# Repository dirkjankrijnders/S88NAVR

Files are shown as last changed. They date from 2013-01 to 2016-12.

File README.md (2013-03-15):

S88NAVR
=======

An implementation of the S88-N protocol for Atmel Atmega[8/48/88/168/328] microcontrollers. So far, an Arduino Pro Mini version and the actual board have been tested.

Goal
----

The goal is the make small, cheap reliable feedback modules for the S88 system. Hence choice for the microcontroller, one IC instead of the three discreet ones. The choice for SMD technology for a small board with components on both sides, as most will be hand soldered. The reliability comes from the use of the S88-N Cabling and timing, input diodes and a RC input network. If wanted the RC network and diodes can be short to minimize cost when needed, leaving 10 components (2 connectors, an uc, two caps and five resistors). The RC-network kills spike, the 1N4148 does the same ensuring the reliability of the detection, the big diode make sure the "detection" rail acts a as a ground return as well ensuring reliable operation of the track. 
The board is designed for production by cheap production houses like seeedstudio's PCB service. Goal is to stay under €5.00 for the fully build PCB.

State
-----
The parts for the first revision (Rev. 0) have been ordered, including the PCB at Seeedstudios. See below for an image and a BOM of the non-standard parts.
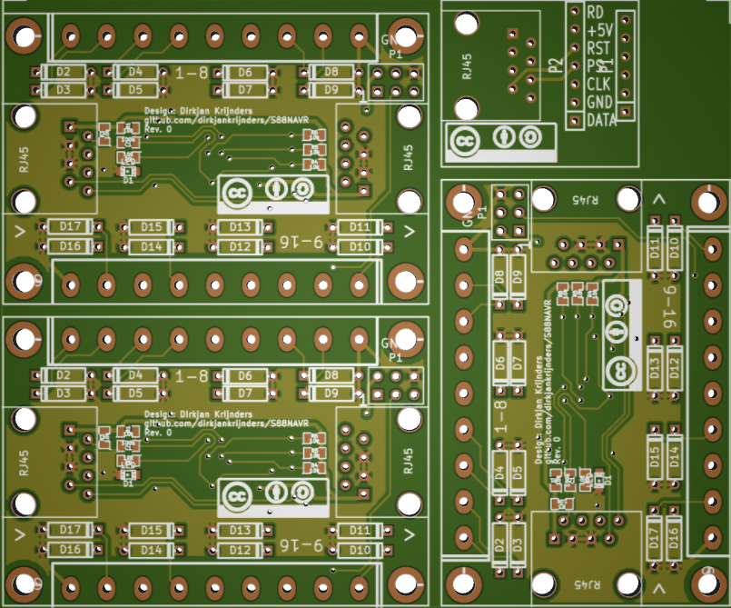
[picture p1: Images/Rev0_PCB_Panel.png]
. The total is still enough under €5.00 to fit the passives and stand-offs (no prices because then come from my stock).
<table>
<tr>
<th>Part</th><th>#</th><th>Conrad #</th><th>price* (€)</th>
</tr>
<tr><td>IC1</td><td>1</td><td>154273</td><td>2.41</td></tr>
<tr><td>P2,P3</td><td>2</td><td>731817+731830</td><td>0.71</td></tr>
<tr><td>J1,J2</td><td>2</td><td>716232</td><td>0.58</td></tr>
<tr><td>PCB</td><td>1</td><td>Seeed</td><td>0.64</td></tr>
<tr><td colspan=3>Total</td><td>4.34</td></tr>
</table>
*When ordering 10+ quantities

The boards came back from Seeedstudios and they work, only one small issue where a track was not connected, update in as rev 0.1. Only in the kicad files, the change is too small to spin a new board.
LICENSE
-------

Both hardware and firmware are placed under the Creative Commons Attribution-ShareAlike 3.0 Unported License. See <http://creativecommons.org/licenses/by-sa/3.0/> and License.txt for more details.

Copyright 2013
Dirkjan Krijnders
<dirkjan@krijnders.net>

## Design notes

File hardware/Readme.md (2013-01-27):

Making production gerbers
=========================

Exporting gerbers from kicad
----------------------------
To create gerbers for a PCB, open the .brd or .kicad\_pcb file in pcbnew. Choose "plot" from the "file" menu. Set the output directory to "Outputs/Rev_x" where x is the current revision number. Also create a drill file is that same directory, with the following settings:

- Units: Inch
- Suppress leading zeros
- Drill Map File Format: Gerber
- No options checked
- Drill origin: Absolute

You should now have at least 6 gerbers and a drill file in the "Outputs/Rev_x" directory.

Merging gerbers into a panel
----------------------------

Install gerbmerge (<http://ruggedcircuits.com/gerbmerge/>). Check the settings in "template_main", especially the revision number in the path. Then generate the gerbmerge config file use the script:

`./make-gerbmerge-config.sh S88-S88N S88P3 >> gerbmerge-config`

Where the last arguments are the basename of the gerbers made in the previous step. Make adjustments to the panel-layout as needed and create the merged gerbers:

`python2.7 ~/Projects/3rd_party/gerbmerge-1.8/gerbmerge/gerbmerge.py gerbmerge-config panel-layout`

The drill file created by gerbmerge are very minimal and not every program likes them, so fix the .xln with the supplied script:

`./gerbmergexln2drl.sh S88-Panel-Rev0`

where the last argument is the basename of the panel gerbers.

Checking the results
--------------------
check the results with gerbv:

`gerbv <basename>.*`

double check with gerbview:

`gerbview <basename>.*`

triple with an online gerber viewer:

- <http://mayhewlabs.com/3dpcb>

If the output of all programs looks good, you're in good shape for production!

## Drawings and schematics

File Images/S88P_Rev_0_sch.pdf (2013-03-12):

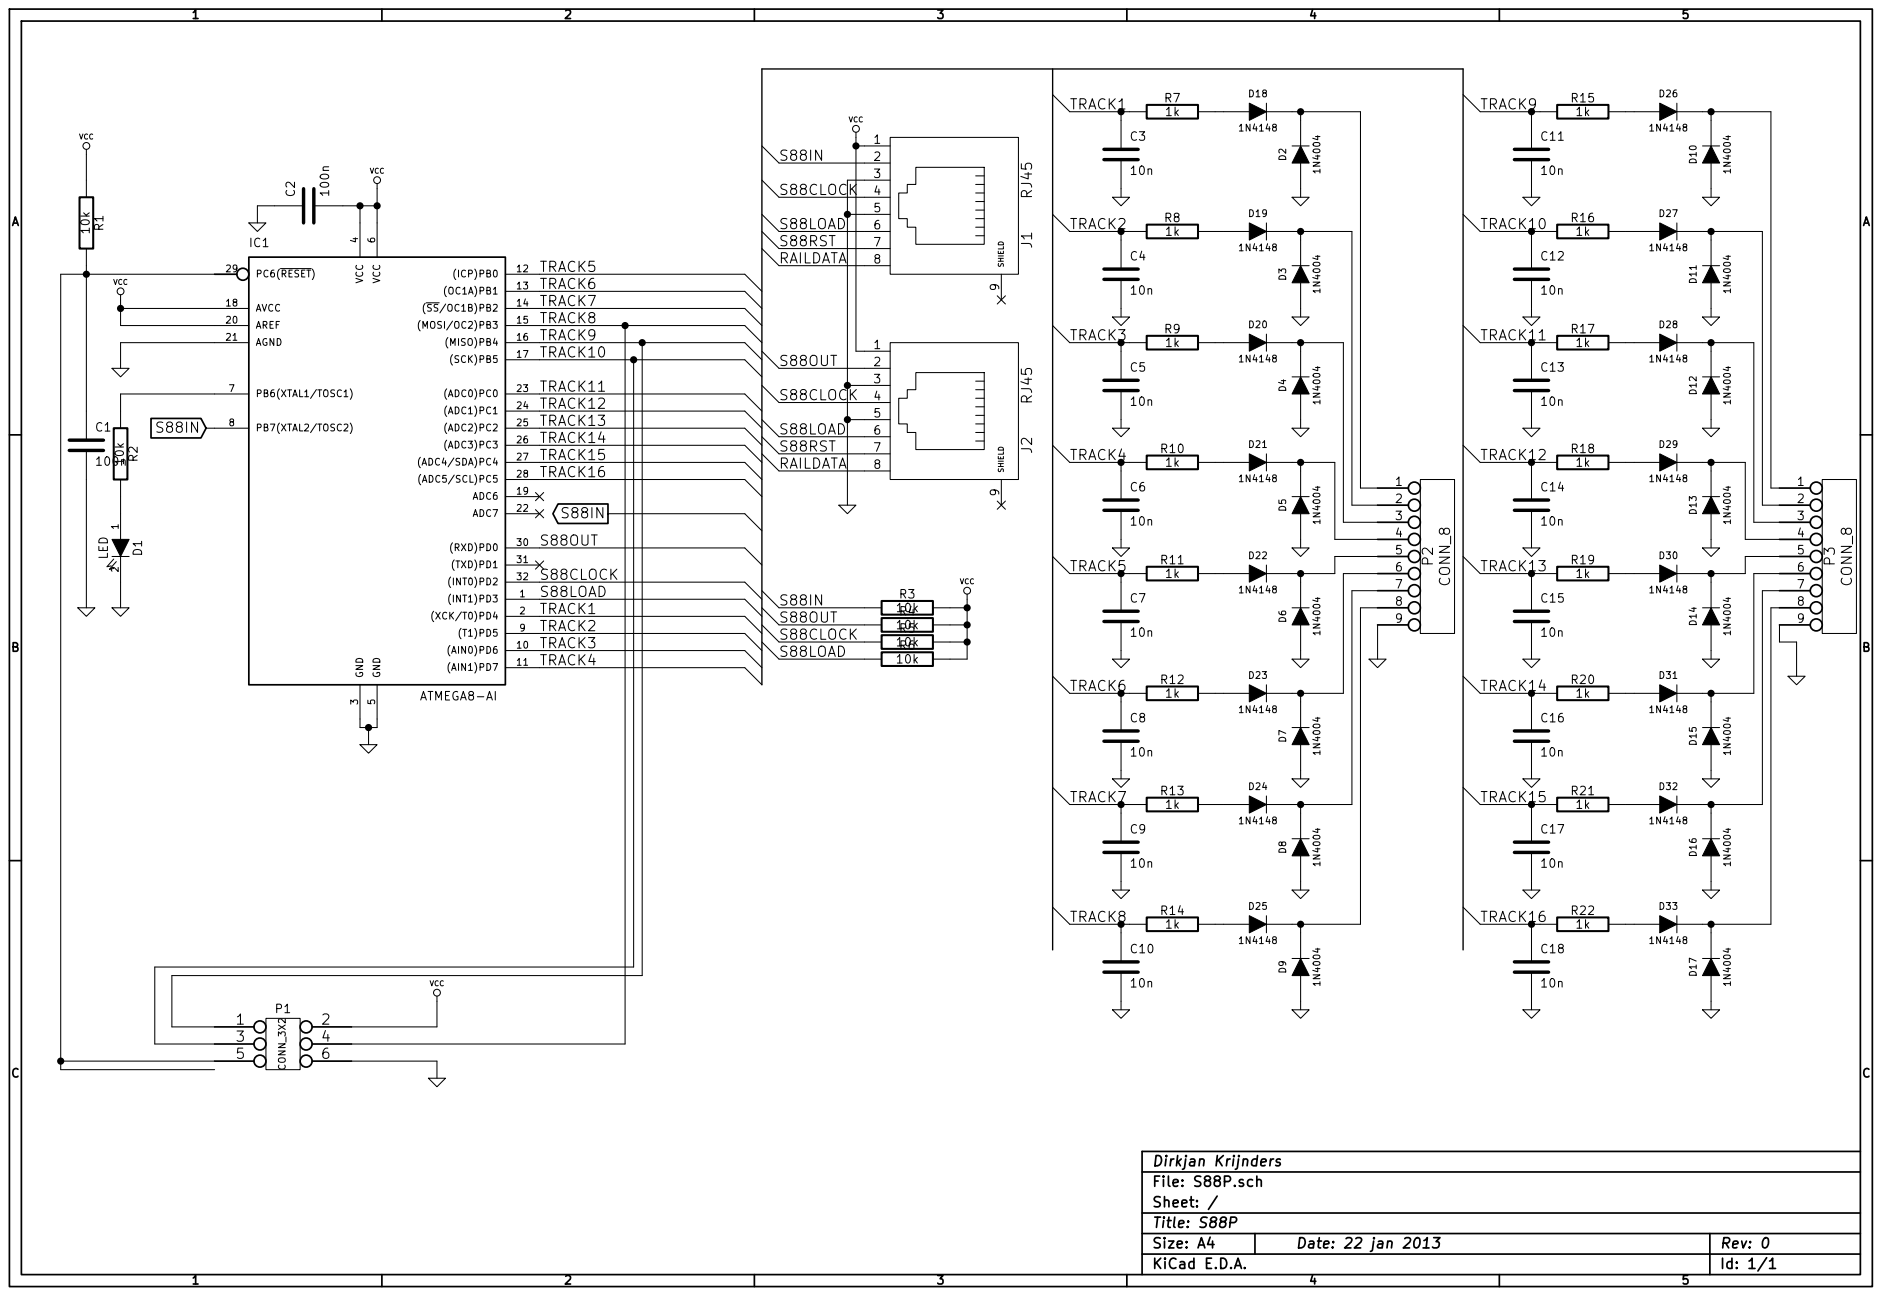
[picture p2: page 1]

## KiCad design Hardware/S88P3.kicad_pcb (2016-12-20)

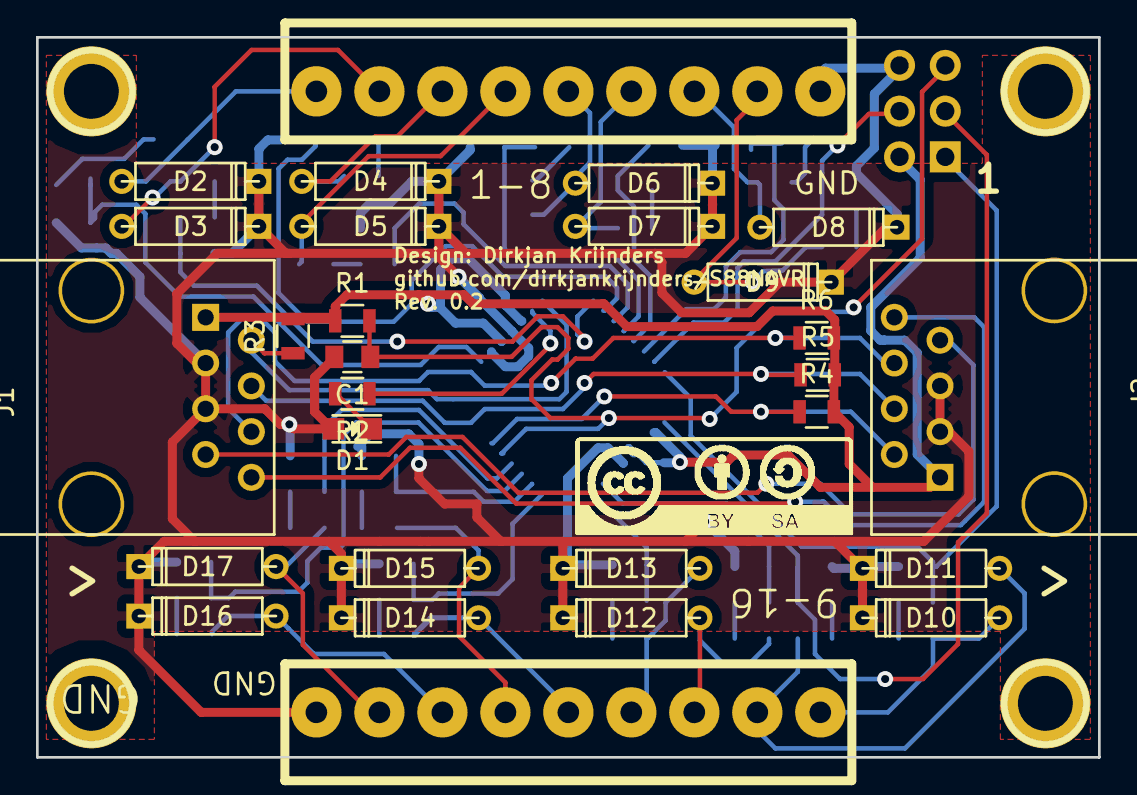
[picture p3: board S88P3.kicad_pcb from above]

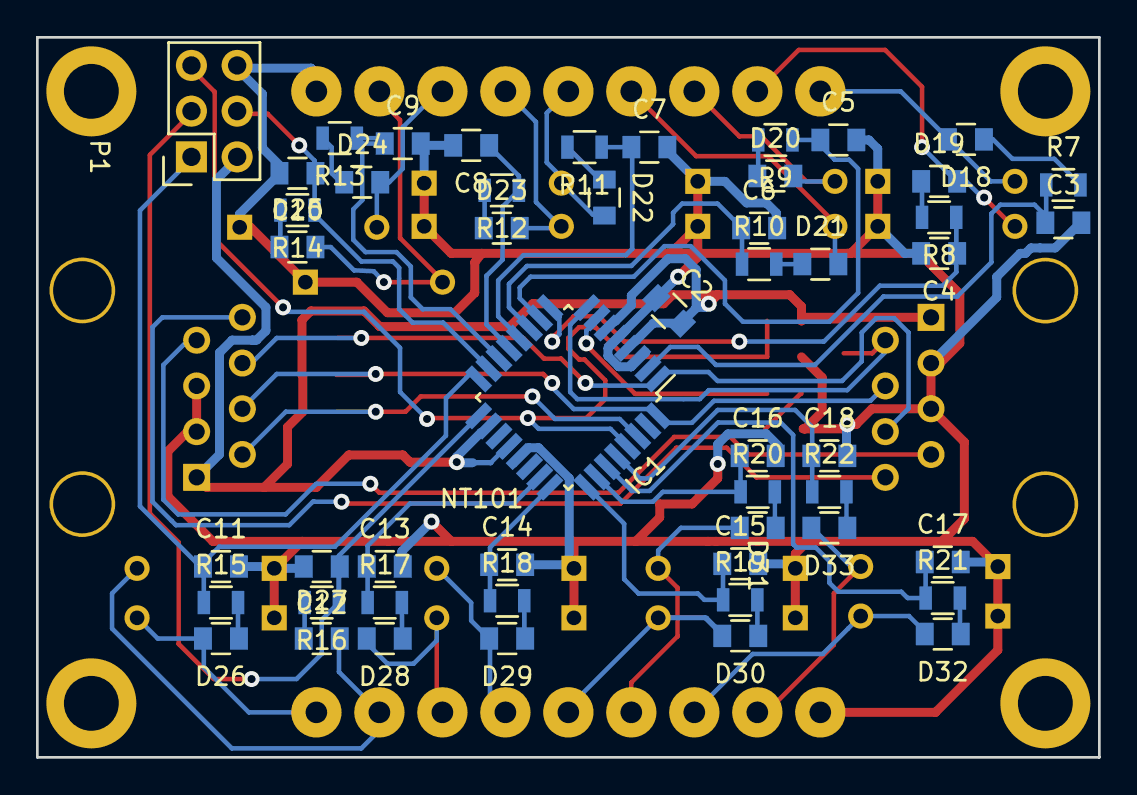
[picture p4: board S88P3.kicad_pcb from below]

Board: 2 copper layers, 59.0 x 40.0 mm, 80 parts (52 on the bottom side), 60 nets.

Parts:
C1, C2: 100n; C_0805
C3, C4, C5, C6, C7, C8, C9, C10, C11, C12, C13, C14, C15, C16, C17, C18: 10n; C_0805
D1: LED; LED-0805
D2, D3, D4, D5, D6, D7, D8, D9, D10, D11, D12, D13, D14, D15, D16, D17: 1N4004; D3
D18, D19, D20, D21, D22, D23, D24, D25, D26, D27, D28, D29, D30, D31, D32, D33: 1N4148; C_0805
IC1: ATMEGA8-AI; TQFP-32_7x7mm_Pitch0.8mm
J1, J2: RJ45; RJ45_8
NT101: Nettie; nettie_0.3mm
P1: CONN_3X2; Socket_Strip_Straight_2x03
P2, P3: CONN_8; 9PIN_SC_RM3.5
R1, R2, R3, R4, R5, R6: 10k; R_0805
R7, R8, R9, R10, R11, R12, R13, R14, R15, R16, R17, R18, R19, R20, R21, R22: 1k; R_0805

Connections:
/RAILDATA: J1.8, J2.8
/S88CLOCK: IC1.32, J1.4, J2.4, R5.1
/S88LOAD: IC1.1, J1.6, J2.6, R6.1
/S88OUT: IC1.30, J2.2, R4.1
/S88RST: J1.7, J2.7
/TRACK1: C3.1, IC1.2, R7.1
/TRACK2: C4.1, IC1.9, R8.1
/TRACK3: C5.1, IC1.10, R9.1
/TRACK4: C6.1, IC1.11, R10.1
/TRACK5: C7.1, IC1.12, R11.1
/TRACK6: C8.1, IC1.13, R12.1
/TRACK7: C9.1, IC1.14, R13.1
/TRACK8: C10.1, IC1.15, P1.4, R14.1
/TRACK9: C11.1, IC1.16, P1.1, R15.1
/TRACK10: C12.1, IC1.17, P1.3, R16.1
/TRACK11: C13.1, IC1.23, R17.1
/TRACK12: C14.1, IC1.24, R18.1
/TRACK13: C15.1, IC1.25, R19.1
/TRACK14: C16.1, IC1.26, R20.1
/TRACK15: C17.1, IC1.27, R21.1
/TRACK16: C18.1, IC1.28, R22.1
GND: C1.2, C2.1, C3.2, C4.2, C5.2, C6.2, C7.2, C8.2, C9.2, C10.2, C11.2, C12.2, C13.2, C14.2, C15.2, C16.2, C17.2, C18.2, D1.2, D2.1, D3.1, D4.1, D5.1, D6.1, D7.1, D8.1, D9.1, D10.1, D11.1, D12.1, D13.1, D14.1, D15.1, D16.1, D17.1, IC1.3, IC1.5, IC1.21, J1.3, J1.5, J2.3, J2.5, P1.6, P2.9, P3.9
unnamed: C1.1, IC1.29, P1.5, R1.2
unnamed: D1.1, R2.2
unnamed: D10.2, D26.2, P3.1
unnamed: D11.2, D27.2, P3.2
unnamed: D12.2, D28.2, P3.3
unnamed: D13.2, D29.2, P3.4
unnamed: D14.2, D30.2, P3.5
unnamed: D15.2, D31.2, P3.6
unnamed: D16.2, D32.2, P3.7
unnamed: D17.2, D33.2, P3.8
unnamed: D18.1, R7.2
unnamed: D2.2, D18.2, P2.1
unnamed: D19.1, R8.2
unnamed: D3.2, D19.2, P2.2
unnamed: D20.1, R9.2
unnamed: D4.2, D20.2, P2.3
unnamed: D21.1, R10.2
unnamed: D5.2, D21.2, P2.4
unnamed: D22.1, R11.2
unnamed: D6.2, D22.2, P2.5
unnamed: D23.1, R12.2
unnamed: D7.2, D23.2, P2.6
unnamed: D24.1, R13.2
unnamed: D8.2, D24.2, P2.7
unnamed: D25.1, R14.2
unnamed: D9.2, D25.2, P2.8
unnamed: D26.1, R15.2
unnamed: D27.1, R16.2
unnamed: D28.1, R17.2
unnamed: D29.1, R18.2
unnamed: D30.1, R19.2
unnamed: D31.1, R20.2
unnamed: D32.1, R21.2
unnamed: D33.1, R22.2
unnamed: IC1.7, R2.1
unnamed: IC1.20, NT101.2
S88IN: IC1.8, J1.2, R3.1
VCC: C2.2, IC1.4, IC1.6, IC1.18, J1.1, J2.1, NT101.1, P1.2, R1.1, R3.2, R4.2, R5.2, R6.2

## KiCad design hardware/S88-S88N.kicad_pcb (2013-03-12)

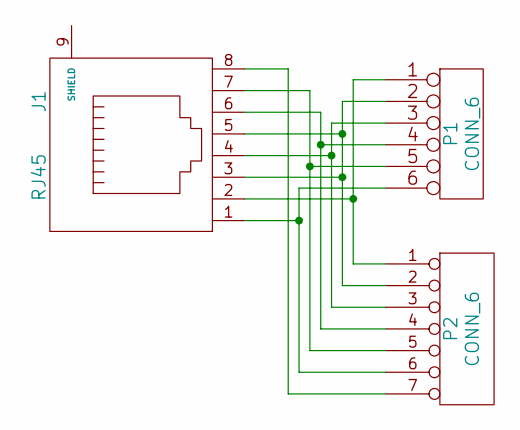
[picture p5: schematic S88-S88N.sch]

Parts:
J1: RJ45
P1, P2: CONN_6

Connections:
unnamed: J1.6, P1.4, P2.4
unnamed: J1.7, P1.5, P2.5
unnamed: J1.1, P1.6, P2.6
unnamed: J1.8, P2.7
unnamed: J1.2, P1.1, P2.1
unnamed: J1.3, J1.5, P1.2, P2.2
unnamed: J1.4, P1.3, P2.3

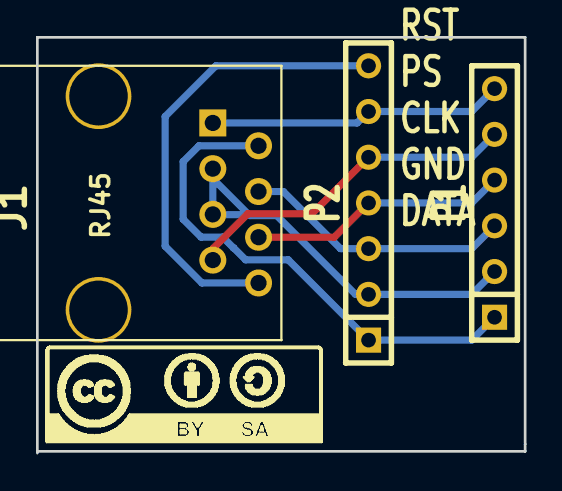
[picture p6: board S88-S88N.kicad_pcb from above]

Board: 2 copper layers, 27.1 x 23.1 mm, 3 parts (0 on the bottom side), 7 nets.

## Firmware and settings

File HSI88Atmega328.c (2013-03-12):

#include <avr/io.h>
#include <avr/interrupt.h> 
#include <string.h>

#define PSC 256
#define T0CNT 15
#define START_TIMER0 TCCR0B |= (1<<CS00)|(1<<CS01) 
#define STOP_TIMER0  TCCR0B &= 0B11111000 


// PIN OUT S88N
#define CLK PD2
#define PS PD3
#define DATA PD4
#define RST PD6

// Defines for USART
#define USART_BAUDRATE 9600
#define UBRR_VALUE (((F_CPU / (USART_BAUDRATE * 16UL))) - 1)

int modules[3] = {2*2, 0,0};
int CLKC = 16*1;
enum states {
	IDLE = 0, 
	RESET, 
	PRELOAD, 
	POSTLOAD, 
	CLOCK
};

enum mainstates {
	START = 0,
	RECIEVECMD,
	READS88
};

enum readstates {
	FULL = 0,
	DIFF
};

enum modes {
	TERM = 0,
	BIN
};


#define cTERM  't'
#define cINIT  's'
#define cFULL  'm'
#define cVERS  'v'

const char versionInfo[40] = "AVR88-HSI 0.1\r\0";

char commandBuffer[8]; // Max 5 in binary mode, 8 in terminal mode
int commandBufferIndex = 0;
char sendBuffer[18]; // Version string is longest 
int state = IDLE;
int mode = BIN;
int mainState = START;
int readState = FULL;

int data[2][62]; // 31 Modules with 16 bits, so 62 8 bytes... Two buffers to calculate the differences
int currentBuffer = 0;
int diffBuffer = 1;
int module = 0;
int bit = 0;
int t = 0;

void USART0SendByte(uint8_t u8Data);
void USART0SendCString(char* str);
void cmdDispatcher();
 
ISR(TIMER0_COMPA_vect) {
	if (CLKC ==0 && state == CLOCK)  {
		CLKC = 16*modules[0];
		state = IDLE;
		// Stop the clock
		STOP_TIMER0;
		// Disable RX interupt and fire command dispatcher;
		// UCSR0B &= ~((1<<RXEN0)|(1<<RXCIE0));
		// Enable TX
		UCSR0B |= (1<<TXEN0);
		int i = 0;
		USART0SendByte('i');
		diffBuffer = currentBuffer ^ 1;
		if (readstate == FULL) {
			for (i = 0; i < modules[0]/2; i++) {
				USART0SendByte(i+1);
				USART0SendByte(data[currentBuffer][i*2]);
				USART0SendByte(data[currentBuffer][(i*2)+1]);
				data[diffBuffer][i*2] = 0;
				data[diffBuffer][(i*2)+1] = 0;
				currentBuffer = diffBuffer;
			}
		} else {
			int changedModules = 0;
			for (i = 0; i < modules[0]/2; i++) {
				// We reuse the diffBuffer for the data to send, the data itself is not interesting once the difference check has been made.
				if ((data[currentBuffer][i*2] != data[diffBuffer][i*2]) | (data[currentBuffer][(i*2)+1] != data[diffBuffer][(i*2)+1])) {
					changeModules++;
					data[diffBuffer][changedModules*2] = data[currentBuffer][i*2];
					data[diffBuffer][(changedModules*2)+1] = data[currentBuffer][(i*2)+1];
				};
			}
			// Send diffBuffer
			USART0SendByte(changedModules);
			for (i = 0; i < changedModules; i++) {
				USART0SendByte(i);
				USART0SendByte(data[diffBuffer][i*2]);
				USART0SendByte(data[diffBuffer][(i*2)+1]);
			}		
			// Clear the oldest buffer
			for (i = 0; i < modules[0]/2; i++) {
				data[diffBuffer][i*2] = 0;
				data[diffBuffer][(i*2)+1] = 0;
			};

			// Swap buffers
			currentBuffer = diffBuffer;
		};
		USART0SendByte('\r');
		// Disable TX
		UCSR0B &= ~(1<<TXEN0);

	} else if (state == IDLE) { // && (PIND & (1 << RST))) { // Pulse reset
		PORTD ^= (1<<RST); // Toggle the pin
		state = RESET;
	} else if (state == RESET) {
		PORTD ^= (1<<RST); // Toggle the pin
		state = PRELOAD;
		module = 0;
	} else if (state == PRELOAD && !(PIND & (1 << PS))) {
		PORTD ^= (1<<PS);
	} else if (state == PRELOAD && (PIND & (1 << PS))) {
		CLKC--;
		PORTD ^= (1<<CLK); // Toggle the pin (up)
		state = POSTLOAD;
	} else if (state == POSTLOAD && (PIND & (1 << CLK))) {
		CLKC--;
		PORTD ^= (1<<CLK); // Toggle the pin (down)
		bit = 0;
		t = (PIND & (1<<DATA)) ? 1 : 0 ;
		data[module] |= t;
	} else if (state == POSTLOAD && !(PIND & (1 << CLK))) {
		PORTD ^= (1<<PS);
		state = CLOCK;
	} else if (state == CLOCK) {
		CLKC--;
		PORTD ^= (1<<CLK); // Toggle the pin
		if  (!(PIND & (1 << CLK))) // Down flank
		{ 
			bit++;
			if (bit > 7) {
				module++;
				bit = 0;
			}
			t = (PIND & (1<<DATA)) ? 1 : 0 ;
			data[currentBuffer][module] |= (t << bit);
		}
	}
}

ISR(USART_RX_vect) {
	commandBuffer[commandBufferIndex] = UDR0;
	if (commandBuffer[commandBufferIndex] == '\r') { // End of command
		// Disable RX interupt and fire command dispatcher;
		UCSR0B &= ~((1<<RXEN0)|(1<<RXCIE0));
		// Enable TX
		//UCSR0B |= (1<<TXEN0);
		cmdDispatcher();
		// Disable TX
		// UCSR0B &= ~(1<<TXEN0);
		// Enable RX interupt
		// UCSR0B |= ((1<<RXEN0)|(1<<RXCIE0));
		commandBufferIndex = 0;
	} else {
		mainState = RECIEVECMD;
		// Echo
		//	USART0SendByte(commandBuffer[commandBufferIndex] );
		commandBufferIndex++;
	}
}

void cmdDispatcher() {
	switch (commandBuffer[0]) {
	case cTERM: // Mode change, ignored only binary supported, reply "t0"
		strcpy(sendBuffer, "t0\r\0");
		//sendBuffer = {'t', '0', '\r', '\0'};
		mainState = START;
/*		USART0SendByte('t');
		USART0SendByte('0');
		USART0SendByte('\r');*/
		break;
	case cINIT:
		modules[0]=(int)commandBuffer[1]*2;
		modules[1]=(int)commandBuffer[2]*2;
		modules[2]=(int)commandBuffer[3]*2;
		CLKC = 16*modules[0];
		sendBuffer[0] = 's';
		sendBuffer[1] = (char)((modules[0]+modules[1]+modules[2])/2);
		sendBuffer[2] = '\r';
		sendBuffer[3] = '\0';
		state = IDLE;
		START_TIMER0;
		mainState = READS88;
		readState = FULL;
		break;
	case cFULL:
		state = IDLE;
		START_TIMER0;
		mainState = READS88;
		readState = FULL;
		break;
	case cVERS:
		strcpy(sendBuffer, versionInfo);
		mainState = START;
		break;
	}
	USART0SendCString(sendBuffer);
};

void setupt0() {
	TIMSK0 = _BV(OCIE0A); // Interrupt on T0CNT == COMPA
	TCCR0A = _BV(WGM01);  // Timer clear on Compare match
	OCR0A = 8; //T0CNT; // Set the compare value
}

void setupUSART(){
	// Set baud rate
	UBRR0 = UBRR_VALUE;
	// Set frame format to 8 data bits, no parity, 1 stop bit
	UCSR0C=(1<<7)|(1<<2)|(1<<1);
	//enable receptiondd
};

void USART0SendByte(uint8_t u8Data)
{
	//wait while previous byte is completed
	while(!(UCSR0A&(1<<UDRE0))){};
	// Transmit data
	UDR0 = u8Data;
}

void USART0SendCString(char* str) {
	UCSR0B |= (1<<TXEN0);
	int i = 0;
	while (str[i] != '\0')
		USART0SendByte(str[i++]);
}

int main() {
	CLKC = 16*modules[0];
	/* Main timer is TIMER0. PRESCALER will set to 256 */
	setupt0();

	setupUSART();
 	// Arduino pin 4/PD4 as output
	DDRD = _BV(CLK) | (1 << RST) | (1 << PS);

	sei();

	while(1) {
		switch (mainState) {
		case START:
			// Enable recieve of commands, disable TX
			UCSR0B |= ((1<<RXEN0)|(1<<RXCIE0));
		break;
		case READS88:
			// Disable RX, enable TX
			UCSR0B &= ~((1<<RXEN0)|(1<<RXCIE0));
			UCSR0B |= (1<<TXEN0);

			// Start timer0
			START_TIMER0;
		break;
		}
	};
	return 0;
}

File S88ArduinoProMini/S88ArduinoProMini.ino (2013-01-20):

//#define FCPU 8000000
#define LOAD INT1

#include <avr/interrupt.h>

volatile uint16_t buffer = 43690;
uint16_t msb = (1 << 15);
bool t;
uint8_t m = 0;

ISR(INT0_vect) {
  cli();
  if (((PIND & 0b00000100) == 0b00000100)) {   // If rising edge, read S88DATAIN
    t = (PIND & 16) ? msb : 0;
    //Serial.println(t);
    buffer |= t;
  } else {   // If falling edge, write S88DATAOUT
    if ((buffer & 1) == 1) {
      PORTD |= 0b11111111; //(1 << 6);
    } else {
      PORTD &= 0b11011111;
    }
    // Shift register and add value;
    buffer = (buffer >> 1);// | t;
  };
  
 
  sei();
}

ISR(INT1_vect) { // LOAD
  cli();
  buffer = 43690;
//  Serial.print('i');
  sei();
}

void setup() {
  Serial.begin(115200);
//  Serial.println("Hallo!");

//  pinMode(13, OUTPUT);
//  pinMode(5, INPUT);
  DDRB |= (1 << 5); // Arduino Pro Mini pin 13 as output
  DDRD = 0b00100010; // Arduino Pro Mini TX and pin 6 as output 
  EICRA |= (1 << ISC00);    // set INT0 to trigger on ANY logical change
  EIMSK |= (1 << INT0);     // Turns on INT0
  EICRA |= (1 << ISC10);    // set INT1 to trigger rising edge
  EICRA |= (1 << ISC11);    
  EIMSK |= (1 << INT1);     // Turns on INT1
  sei();
  PORTB |= (1 << 5); // Arduino Pro Mini pin 13 HIGH
};  

void loop(){
//delay(300);
//  PORTB ^= (1 << 5); // Arduino Pro Mini pin 13 Toggle
};

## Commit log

2013-01-20 Arduino Pro Mini version
2013-01-22 First full schematic and board layout
    [S88P.sch, S88P3.brd]
2013-01-23 - Cleaned up board - Added ground plane - Added CC-BY-SA logo - Added information text
    [S88P3.brd]
2013-01-23 - Added schematic for converter board
    [S88-S88N.sch]
2013-01-23 Added board and support files for converter board
    [S88-S88N.kicad_pcb]
2013-01-23 Updated Silkscreen
    [S88-S88N.kicad_pcb]
2013-01-23 Added standoff holes
    [S88P3.brd]
2013-01-25 Files to generate the production gerbers
2013-01-25 Made the board slightly less wide, added arrows on silkscreen
    [S88P3.brd]
2013-01-25 Annotated schematic
    [S88-S88N.sch]
2013-01-27 Added image of the pcb panel for Rev.0
2013-01-27 Added current state of the project
2013-01-27 Completed current state
2013-01-27 Gerber and panel creation manual
2013-01-28 Added pdf of rev 0 schematic
2013-02-02 Arduino wants its files in a directory with the same name
2013-02-02 Initial implementation of S88 to UART bridge
2013-02-06 Start of UART implementation
2013-02-18 - Cleanup\r- Used pin definitions
2013-02-18 Rename c file to reflect μc use
    Flash LED
2013-02-19 Fixed short between GND and Data
    [S88-S88N.kicad_pcb, S88-S88N.sch]
2013-02-22 Added assembler version of firmware
2013-02-25 Switched low/high around in the buffer...
2013-03-12 Fixed a missing trace. Fixes #1
    [S88P3.brd]
2013-03-13 Updated revision number on board
    [S88P3.brd]
2013-03-15 Start of converter redesign
    [S88-S88N.sch]
2013-03-16 Fixed remaining silkscreen labels
    [S88P3.brd]
2013-04-01 Added kicad component cache
2014-09-24 Schematic cleanup
    [S88P.sch]
2015-12-07 Updates for newer standard schematic symbols
    [S88P.sch]
2015-12-07 Kicad cache and rescue libs update
2016-12-20 Removed “special” library which is not available anymore and not used anyway
2016-12-20 Fixed capacitors and resistor connections
    [S88P.sch]
2016-12-20 More connections and a net tie, ERC now passes
    [S88P.sch]
2016-12-20 Rename and update
    [S88P3.sch]
2016-12-20 Fixed footprints
    [S88P3.sch]
2016-12-20 Format upgrade
    [S88P3.brd, S88P3.kicad_pcb]
2016-12-20 Finished component modernisation
    [S88P3.kicad_pcb]
